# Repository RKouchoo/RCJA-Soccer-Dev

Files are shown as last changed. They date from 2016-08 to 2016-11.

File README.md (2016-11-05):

# RCJA Soccer Dev

#This projecta has now been abandoned as we are no longer using it for next season.
#please do not submit issues as we will not acknowledge them.

@Team Circut Breaker Dev

  First created: 3 / 7 / 2015
  Latest update: 25 / 8 / 2016

  Interesting Link: http://dlnmh9ip6v2uc.cloudfront.net/ - I love this link

  details about the compass sensor can be found on this data sheet http://dlnmh9ip6v2uc.cloudfront.net/datasheets/Sensors/Magneto/HMC5883L-FDS.pdf

  Latest code is being written in the Nationals2016 folder

  ===============
  CURRENT STATE:
  ===============

  WORKING ON CURRENTLY: Hard wiring the new light sensors to robot. Also working on a new check for system, with switches.

  ==============

  KICKER NOTICE:
  currently have not implemented methods for use of a soleniod+transformer/boost converter as i cannot mount it to either of the robots & and dangerous as a high current might get us disqualified (5 AMPS+ OUTPUT)
  
=====================================================  
========================================================

  TODO LIST:

Small Robot:

  - Mount compass
  - Mount kicker stuff
  - Mount booster circuit and work it out
  - write code for the compass to auto align when not much is happening (started compass intialisation)

Big Robot:
- Need to fix why sensors are fucking with us

After State:
  - Put compass on both robots
  
  - work on a random defence timer, robot going back into its half and then strafe defending. (Once compass is known to work, ill have to write stuff - cannot getting working til main movement code decides to work.
    to do with the headings....  oh noes.. requires advanced trig :/).

  - write code for the compass to auto align when not much is happening (started compass intialisation)

  - Dress robot make look pretty (Leds, Lasers, Protection etc)
  
  - create a heading compass system, later when we have two robots we NOTE: i have pre setup the variables
    can use the heading system for robots to return to original location

  CHANGELOG:

  - FIXED: "Issue where the robot will see different bars  behind it, so where 9 would be theres 2 or 9 and would make the robot spam left-right
    facing the wrong way"

    SOLUTION: the bars issue is still happening but has been resolved by changing directions in which the motors move. apparently the motor
    controllers do not like some movements and will go backwards !? kinda problematic.. will investigate after comp.
    
  - ADDED: speed control support for the motor controllers, so we dont tear apart the mat. 

  DROP LIST:

  - Not necessary: Re-Writing Main setup code in a seperate file, debunk the code issue and decide if its a hardware issue
  
  - Too Much overhead and takes CPU cycles: get serial screen working, outputting what would be in the console

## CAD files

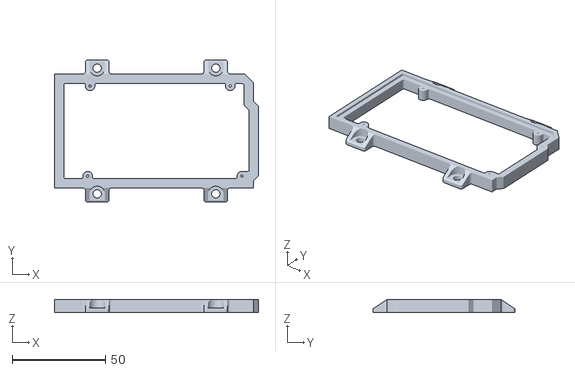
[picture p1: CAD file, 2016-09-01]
Print Files/MEGA_R2_MOUNT.STL
109.2 x 76.2 x 6.99

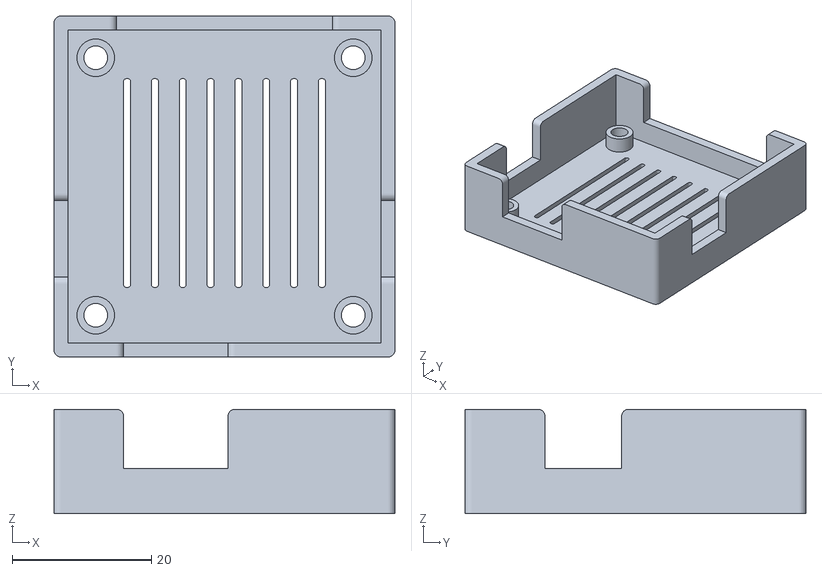
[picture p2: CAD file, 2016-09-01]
Print Files/L298N_-_Motor_driver_holder_-_heatsink.stl
49.0 x 49.0 x 15.0

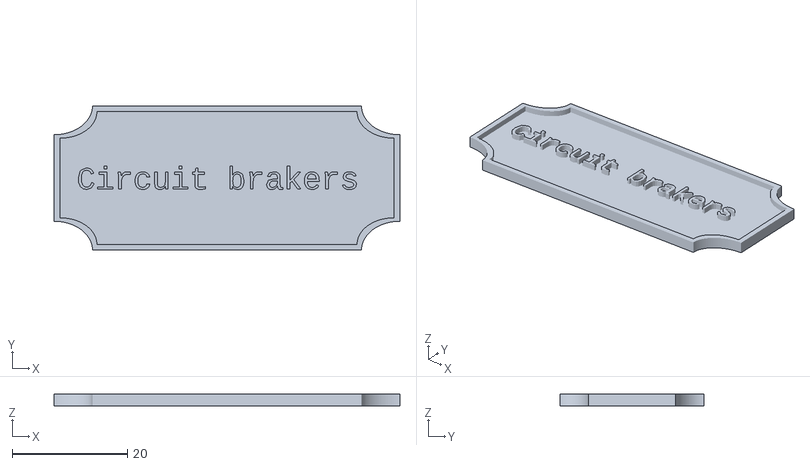
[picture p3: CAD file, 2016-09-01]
Print Files/nametag_20160831-16166-1kobh9q-0.stl
60.0 x 25.0 x 2.00

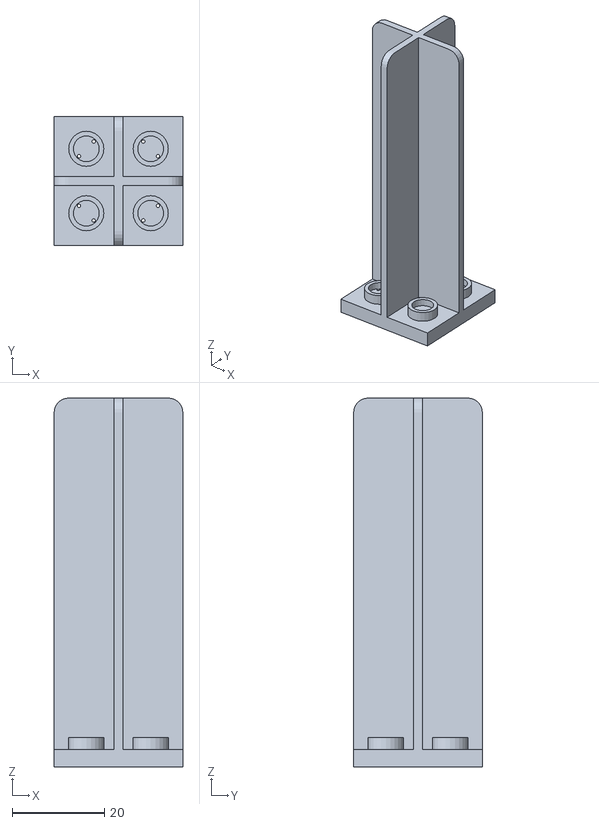
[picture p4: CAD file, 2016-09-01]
Print Files/Compass_Sketch.stl
27.9 x 27.9 x 80.0

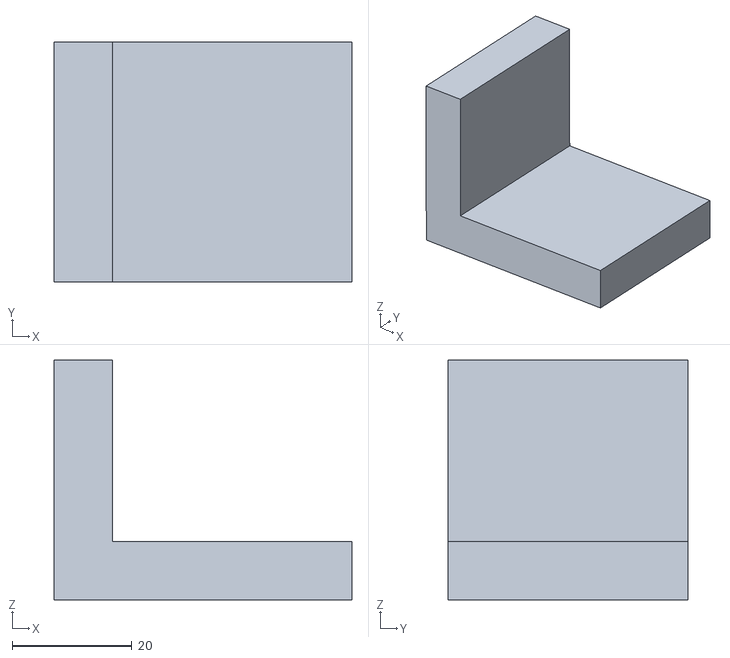
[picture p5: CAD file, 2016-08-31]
Print Files/angle_mount.obj
49.8 x 40.0 x 40.0

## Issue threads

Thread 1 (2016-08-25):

Bad Motor Controller

RKouchoo, 2016-08-25:
Motor controller will be replaced shortly

Closed 2016-08-31.

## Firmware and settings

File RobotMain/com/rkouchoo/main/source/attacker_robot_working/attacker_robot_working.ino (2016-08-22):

/*
 * Opens soccer robot main code set, 
 * Team circut breaker Dev @RKouchoo
 * 
 * First created:  5 / 8 / 2015
 * Latest Update:  22 / 8 / 2016
 * 
 * anything with a " // " next to it means it has been modified or its a comment!             | DAT BOI TEXT ART HERE PLZ |
 * 
 * 
 *        ===============================================
 *        PLEASE READ THE DOCUMENTATION FOR MORE INFO!!!!
 *        ===============================================
 * 
 * 
 */

                        //IMPORTS
 //=======================================================================
 
 #include <Wire.h>
                       //ROBOT MAP
//=======================================================================


  #define CompassAddress 0x1E //compass I2C addresses 
  #define CompassMode 0x02
  #define CompassReadMode 0x00
  #define CompassRegister 0x03
  #define CompassByteLength 6
 

  int CompassX; //compass headings
  int CompassY;
  int CompassZ; //current compass oreintation/direction
  int CompassOriginalDirection_Z; //the original direction that the compass starts in. stored at robot init, used to auto align (LATER OK :/ )

  //details about the compass can be found on this data sheet http://dlnmh9ip6v2uc.cloudfront.net/datasheets/Sensors/Magneto/HMC5883L-FDS.pdf
  
  const int LASER_PIN = 10;     //laser and led power up pins
  const int LED_PIN = 22;
  
  int LightsensorValue = 0;      //where the lightsensor input is stored
  const int LightsensorPin = A0; //lightsensor analog read pin
  int GREEN_VALUE = 2345567;     //colour values which need to be changed, depends on feild lighting !
  int WHITE_VALUE = 3534543;  
  
  boolean IsMovingLeft = false;  //true or false statements used for light sensor & movement
  boolean IsMovingRight = false;
  boolean IsMovingBackward = false;
  boolean IsMovingForward = false;
  
  int DefendCountdown = 10000000; //to be continued, look at documentation
  
  const int MotorMED_POWER = 150;  //can be used for motor setup functions max 255, -- will use when pwm cables are connected
  const int MotorFULL_POWER = 255;
  const int MotorLOW_POWER = 80;
                                
                                  //pwm speed and enable pins for the motor controllers
  const int Motor_EN_S_1_1 = 21;    
  const int Motor_EN_S_1_2 = 22; 
                                
  const int Motor_EN_S_2_1 = 23;
  const int Motor_EN_S_2_2 = 24;
  
  const int Motor1A = 38; //motor input pins A is forward, B is reverse  
  const int Motor1B = 40;
  
  const int Motor2A = 42;
  const int Motor2B = 44;
  
  const int Motor3A = 46;
  const int Motor3B = 48;
  
  const int Motor4A = 50;
  const int Motor4B = 52;

  const int LED_PWM_MAX_RATE = 255; //lighting stuff
  const int LED_PWM_MIN_RATE = 25;
  long LED_RAND;

  const int SOLENOID_PIN = 17; //future ref for transformer & kicker



//==================================================================

void RobotInitLights() {
  pinMode(LED_PIN, OUTPUT);
  LED_RAND = random(LED_PWM_MIN_RATE, LED_PWM_MAX_RATE);
  digitalWrite(LED_PIN, LED_RAND);
 }
 
void initlaser() {
 pinMode(LASER_PIN, OUTPUT);
 digitalWrite(LASER_PIN, HIGH);
}

//                          SEEKER
//==================================================================
#include <Wire.h>

/*
  IRSeeker.ino - A class for the HiTechnic IRSeeker V2 infrared sensor.
  Created by B. Blechschmidt, August 1, 2013.
  Edited by R. Kouchoo - STRICT USE FOR OUR ROBOT
  Clean version released into the public domain.
*/

struct InfraredResult
{
  byte Direction;
  byte Strength;
};

class InfraredSeeker
{
  public:
    static void Initialize();
    static boolean Test();
    static void ReadACRaw(byte* buffer);
    static void ReadDCRaw(byte* buffer);
    static InfraredResult ReadAC();
    static InfraredResult ReadDC();
    static int DirectionAngle(byte Direction);
  private:
    static InfraredResult PopulateValues(byte* buffer);
    static void ReadValues(byte OffsetAddress, byte* buffer);
    static const int Address = 0x10 / 2; //Divide by two as 8bit-I2C address is provided
};

void InfraredSeeker::Initialize()
{
  Wire.begin();
  Wire.beginTransmission(InfraredSeeker::Address);
  Wire.write(0x00);
  Wire.endTransmission();
  while(Wire.available() > 0)
    Wire.read();
}

boolean InfraredSeeker::Test()
{
  Wire.beginTransmission(InfraredSeeker::Address);
  Wire.write(0x08);
  Wire.endTransmission();
  Wire.requestFrom(InfraredSeeker::Address, 16);
  char Manufacturer_Model[16];
  while(Wire.available() < 16);
  for(byte i=0; i < 16; i++)
  {
    Manufacturer_Model[i] = Wire.read();
  }
  while(Wire.available() > 0)
    Wire.read();
  return strncmp(Manufacturer_Model, "HiTechncNewIRDir", 16)==0;
}

void InfraredSeeker::ReadValues(byte OffsetAddress, byte* buffer)
{
  Wire.beginTransmission(InfraredSeeker::Address);
  Wire.write(OffsetAddress);
  Wire.endTransmission();
  Wire.requestFrom(InfraredSeeker::Address, 6);
  while(Wire.available() < 6);
  for(byte i = 0; i < 6; i++)
  {
    buffer[i] = Wire.read();
  }
  while(Wire.available() > 0)
    Wire.read();
}

void InfraredSeeker::ReadACRaw(byte* buffer)
{
  ReadValues(0x49, buffer);
}

void InfraredSeeker::ReadDCRaw(byte* buffer)
{
  ReadValues(0x42, buffer);
}

InfraredResult InfraredSeeker::PopulateValues(byte* buffer)
{
  InfraredResult Data;
  Data.Direction = buffer[0];
  if(buffer[0] != 0)
  {
    if(buffer[0] % 2 == 0)
    {
      Data.Strength = (buffer[buffer[0] / 2] + buffer[buffer[0] / 2 + 1]) / 2;
    }
    else
    {
      Data.Strength = buffer[buffer[0] / 2 + 1];
    }
  }
  else
  {
    Data.Strength = 0;
  }
  return Data;
}

InfraredResult InfraredSeeker::ReadAC()
{
  byte buffer[6];
  ReadACRaw(buffer);
  return PopulateValues(buffer);
}

InfraredResult InfraredSeeker::ReadDC()
{
  byte buffer[6];
  ReadDCRaw(buffer);
  return PopulateValues(buffer);
}

int DirectionAngle(byte Direction)
{
  return Direction * 30 - 150;
}


//============================================================================================
//                                      Motor Functions

void Motor1FWD() {
  digitalWrite(Motor1A, HIGH);
  delay(50);
  digitalWrite(Motor1A, LOW);
}
void Motor1BACKWARD() {
  digitalWrite(Motor1B, HIGH);
  delay(50);  
  digitalWrite(Motor1B, LOW);
  
}

void Motor2FWD() {
  digitalWrite(Motor2A, HIGH);
  delay(50);
  digitalWrite(Motor2A, LOW); 
}
void Motor2BACKWARD() {
  digitalWrite(Motor2B, HIGH);
  delay(50);
  digitalWrite(Motor2B, LOW); 
}

void Motor3FWD() {  
  digitalWrite(Motor3A, HIGH);
  delay(50);
  digitalWrite(Motor3A, LOW);
}
void Motor3BACKWARD() {   
  digitalWrite(Motor3B, HIGH);
  delay(50);
  digitalWrite(Motor3B, LOW);
}


void Motor4FWD() {
  digitalWrite(Motor4A, HIGH);
  delay(50);
  digitalWrite(Motor4A, LOW);
}
 void Motor4BACKWARD() {
  digitalWrite(Motor4B, HIGH);
  delay(50);
  digitalWrite(Motor4B, LOW);
}

//==================================================================

void MoveFORWARD() {
Serial.println("FORWARD");
  digitalWrite(Motor1A, HIGH);
  digitalWrite(Motor2A, HIGH);
  digitalWrite(Motor3A, HIGH);
  digitalWrite(Motor4B, HIGH);
    
// digitalWrite(Motor3A, HIGH);
// digitalWrite(Motor4A, HIGH);

  delay(50);
  
  digitalWrite(Motor1A, LOW);   // digitalWrite(Motor3A, LOW);
  digitalWrite(Motor2A, LOW);   // digitalWrite(Motor4A, LOW);
  digitalWrite(Motor3A, LOW);
  digitalWrite(Motor4B, LOW);                                                                                                       
}

void MoveBACKWARD() {
  digitalWrite(Motor1B, HIGH);
  digitalWrite(Motor2B, HIGH);
  digitalWrite(Motor3B, HIGH);
  digitalWrite(Motor4A, HIGH); 
  delay(50);
  digitalWrite(Motor1B, LOW);
  digitalWrite(Motor2B, LOW);
  digitalWrite(Motor3B, LOW);
  digitalWrite(Motor4A, LOW);
}

void MoveBACKWARDRIGHT() {
  digitalWrite(Motor1B, HIGH);
  digitalWrite(Motor3B, HIGH);
  delay(50);
  digitalWrite(Motor1B, LOW);
  digitalWrite(Motor3B, LOW);
}

void MoveFORWARDRIGHT() {
  digitalWrite(Motor1A, HIGH);
  digitalWrite(Motor3A, HIGH);
delay(50);
  digitalWrite(Motor1A, LOW);
  digitalWrite(Motor3A, LOW);
}


void MoveFORWARDLEFT() {
  digitalWrite(Motor2A, HIGH);
  digitalWrite(Motor4B, HIGH);
delay(50);
  digitalWrite(Motor2A, LOW);
  digitalWrite(Motor4B, LOW);
}
void MoveBACKWARDLEFT() {
  digitalWrite(Motor2B, HIGH);
  digitalWrite(Motor4A, HIGH);
delay(50);
  digitalWrite(Motor2B, LOW); 
  digitalWrite(Motor4A, LOW);
}

void MoveSIDEWAYSRIGHT() {
  digitalWrite(Motor2B, HIGH);
  digitalWrite(Motor3A, HIGH);
  digitalWrite(Motor1A, HIGH);
  digitalWrite(Motor4B, HIGH);
  delay(50);
  digitalWrite(Motor2B, LOW);
  digitalWrite(Motor3A, LOW);
  digitalWrite(Motor1A, LOW);
  digitalWrite(Motor4B, LOW); 
  }

void MoveSIDEWAYSLEFT() {
  digitalWrite(Motor2B, HIGH);
  digitalWrite(Motor4A, HIGH);
  digitalWrite(Motor1B, HIGH);
  digitalWrite(Motor3A, HIGH);
  delay(50);
  digitalWrite(Motor2B, LOW);
  digitalWrite(Motor4A, LOW);
  digitalWrite(Motor1B, LOW);
  digitalWrite(Motor3A, LOW);
  
}

void TurnLEFT() {
  digitalWrite(Motor1A, HIGH);
  digitalWrite(Motor4B, HIGH);
  digitalWrite(Motor2B, HIGH);//
  digitalWrite(Motor3B, HIGH); 
  delay(50); 
  digitalWrite(Motor1A, LOW);
  digitalWrite(Motor4B, LOW);
  digitalWrite(Motor2B, LOW);
  digitalWrite(Motor3B, LOW);//
}

void TurnRIGHT() {
  digitalWrite(Motor2A, HIGH);
  digitalWrite(Motor3B, HIGH);
  digitalWrite(Motor1A, HIGH);
  digitalWrite(Motor4A, HIGH);// 
  delay(50); 
  digitalWrite(Motor2A, LOW);
  digitalWrite(Motor3B, LOW);
  digitalWrite(Motor1A, LOW);
  digitalWrite(Motor4A, LOW);//  
}

 //==========================================================================


void setup() {
  Serial.begin(9600);
   
  RobotInitLights();
  initlaser();
  InfraredSeeker::Initialize();
  
  //initialise compass
  Wire.begin();
  Wire.beginTransmission(CompassAddress); //open comms to the compass
  Wire.write(CompassMode); //select mode register
  Wire.write(CompassReadMode); //continuous measurement mode
  Wire.endTransmission();
  
  Wire.beginTransmission(CompassAddress);
  Wire.write(CompassRegister); //select register 3, X MSB register, these valuses were found on the data sheet.
  Wire.endTransmission();

  //request data from the comnpass
  Wire.requestFrom(CompassAddress, CompassByteLength);

  //request data and set original direction, will be used for auto correct in the future.
  
  if(CompassByteLength<=Wire.available()){
    CompassOriginalDirection_Z = Wire.read()<<8; //Z msb
    CompassOriginalDirection_Z |= Wire.read(); //Z lsb
  }
  
  else;
  {
  Wire.end();
  }
  
  //will create a large amount of delay, try not to use
  Serial.println("DEBUG: Compass start rotation = " + CompassOriginalDirection_Z);
  
  pinMode(Motor1A, OUTPUT);
  pinMode(Motor1B, OUTPUT);
  pinMode(Motor2A, OUTPUT);
  pinMode(Motor2B, OUTPUT);
  pinMode(Motor3A, OUTPUT);
  pinMode(Motor3B, OUTPUT);
  pinMode(Motor4A, OUTPUT);
  pinMode(Motor4B, OUTPUT);

  Serial.println("HiTechnic IRSeeker V2 Initialised, robot has been initialised, loop program will now commence !"); 
  
}

//==========================================================================
    
 //                            I===========I
 //                            I-MAIN LOOP-I
 //                            I===========I 
  
//===========================================================================
  void loop() {

  InfraredResult InfraredBall = InfraredSeeker::ReadAC();
  byte Direction = InfraredBall.Direction;

  //Tell the Compass where to begin reading  directional data
  Wire.beginTransmission(CompassAddress);
  Wire.write(CompassRegister); //select register 3, X MSB register
  Wire.endTransmission();

   Wire.requestFrom(CompassAddress, CompassByteLength);
  
  if(CompassByteLength<=Wire.available()){
    CompassX = Wire.read()<<8; //X msb
    CompassX |= Wire.read(); //X lsb
    
    CompassZ = Wire.read()<<8; //Z msb
    CompassZ |= Wire.read(); //Z lsb
    
    CompassY = Wire.read()<<8; //Y msb
    CompassY |= Wire.read(); //Y lsb
  }

//===========================================================================  
  
  //true and false conditionals setup
  
  boolean IsMovingLeft = false;
  boolean IsMovingRight = false;
  boolean IsMovingBackward = false;
  boolean IsMovingForward = false;
/*
   Serial.println("LightSensor value = " + LightsensorValue);

   //LIGHT & Movement
  
   LightsensorValue = analogRead(LightsensorPin);
  //cond combo 1
   if (LightsensorValue == WHITE_VALUE) 
   {
    if (IsMovingLeft = true)
    {
    MoveFORWARDRIGHT(); 
    Serial.println("boolean - IsMovingLeft - MoveFORWARDRIGHT()");
    }
   }
  //cond combo 2
   if (LightsensorValue == WHITE_VALUE) 
   {
    if (IsMovingRight = true)
    {
    MoveFORWARDLEFT();
    Serial.println("boolean - IsMovingRight - MoveFORWARDLEFT()"); 
    }
   }
  //cond combo 3
   if (LightsensorValue == WHITE_VALUE) 
   {
    if (IsMovingForward = true) 
    {
    MoveBACKWARD();
    Serial.println("boolean - IsMovingForward - MoveBACKWARD()");       
    }
   } 
 */
//==========================================================================


  
   if (InfraredBall.Direction == 1) 
  {                                                                          
  TurnRIGHT();
  Serial.println("TurnLEFT 1");
  boolean IsMovingLeft = true;
  //boolean IsMovingRight = false;
  //boolean IsMovingBackward = false;
  //boolean IsMovingForward = false;
  } 
  
  if (InfraredBall.Direction == 2)
  {
  TurnRIGHT();  
  Serial.println("TurnLeft 2");  //STRAFE HERE  
  boolean IsMovingLeft = true;
  //boolean IsMovingRight = false;
  //boolean IsMovingBackward = false;
  //boolean IsMovingForward = false;
  }
  
  if (InfraredBall.Direction == 3)
  {
  MoveFORWARDLEFT();
  Serial.println("MoveFORWARDLEFT 3");
  boolean IsMovingLeft = true;
  //boolean IsMovingRight = false;
  //boolean IsMovingBackward = false;
  //boolean IsMovingForward = false;
  }
  
  if (InfraredBall.Direction == 4)
  {
  MoveFORWARD();
  Serial.println("MoveFORWARD 4");
  //boolean IsMovingLeft = false;
  //boolean IsMovingRight = false;
  //boolean IsMovingBackward = false;
  boolean IsMovingForward = true;
  }
  
  if (InfraredBall.Direction == 5)
  {
  MoveFORWARD();
  Serial.println("MoveFORWARD 5");
  //boolean IsMovingLeft = false;
  //boolean IsMovingRight = false;
  //boolean IsMovingBackward = false;
  boolean IsMovingForward = true;
  }
  
  if (InfraredBall.Direction == 6)
  {
  MoveFORWARD();
  Serial.println("MoveFORWARD 6");
  //boolean IsMovingLeft = false;
  //boolean IsMovingRight = false;
  //boolean IsMovingBackward = false;
  boolean IsMovingForward = true; 
  }
  
  if (InfraredBall.Direction == 7)
  {
  MoveFORWARDRIGHT(); 
  Serial.println("MoveFORWARDRIGHT 7"); 
  //boolean IsMovingLeft = false;
  boolean IsMovingRight = true;
  //boolean IsMovingBackward = false;
  //boolean IsMovingForward = false;
  }
  
  if (InfraredBall.Direction == 8)
  {
  TurnLEFT();
  Serial.println("TurnRight 8");  //STRAFE HERE
  //boolean IsMovingLeft = false;
  boolean IsMovingRight = true;
  //boolean IsMovingBackward = false;
  //boolean IsMovingForward = false;
  }
  
  if (InfraredBall.Direction == 9)
  {
  TurnLEFT();
  Serial.println("TurnRIGHT 9");
  //boolean IsMovingLeft = false;
  boolean IsMovingRight = true;
  //boolean IsMovingBackward = false;
  //boolean IsMovingForward = false;
  }

//==================================================================

  if (InfraredBall.Direction == 0)
  {
  Serial.println("Yo theres no ball !?!??! - TurnRIGHT()");
  TurnRIGHT();
  boolean IsMovingRight = true;

  }  
}

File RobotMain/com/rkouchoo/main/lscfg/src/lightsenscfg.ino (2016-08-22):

#include <Arduino.h>

int sensorPin = A0; // select the input pin for ldr
int sensorValue = 0; // variable to store the value coming from the sensor
int buttonIn = 6;
int buttonOut = 5;
int laser = 10;

void setup() {
  pinMode(buttonIn, INPUT);
    pinMode(buttonOut, OUTPUT);
    pinMode(laser, OUTPUT);
Serial.begin(9600); //sets serial port for communication
}
void loop() {
  digitalWrite(buttonOut, HIGH);
  digitalWrite(laser, HIGH);

sensorValue = analogRead(sensorPin); // read the value from the sensor
Serial.println(sensorValue); //prints the values coming from the sensor on the screen

//delay(1000);
}

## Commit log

2016-08-22 many many changes.
    - Support for speed control
    - reversed motor orientations in loop
    - data logging is under way
    - partially wrote lightsensor movement
    - trying to fix turn functions when sensor approaches near
    you can find the main class at:
    /RobotMain/com/rkouchoo/main/Atom-PlatIO/src/attacker_robot_working.ino
    I have changed to Atom IDE with PlatIO as it is easier to integrate and write code in, with intelligent completion.
    [Documentation.ino, OpenSource.ino, Robot_Code_simple_test.ino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]
2016-08-24 Fixed Speed Control, fixed delay
    Fixed robot speed control with analogWrite and delay has been moved to bottom of the loop.
    [Documentation.ino, attacker_robot_working.ino]
2016-08-25 Added new code for smaller robot
    - added motor ports
    - added setup and loop
    * currently adding seeker class
2016-08-25 Added Motor speed support
    currently working movements
2016-08-25 Added Updated movement control.
    didn't add to main class as was written on a separate machine. will merge soon
    [updated_movement_control.ino]
2016-08-31 added new file to 3D print
    angle mounts for velcro walls
    [angle_mount.obj]
2016-09-01 Added My current files for 3D printing
    [Compass_Sketch.stl, L298N_-_Motor_driver_holder_-_heatsink.stl, MEGA_R2_MOUNT.STL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]
2016-09-01 FixedTestFor Ball Added CheckIfHasBall
    added CheckIfHasBall, fixed test for ball
    [SmallAttacker.ino]
2016-09-01 fixed a bug
    boolean HasBall = false;
    was originally set to true
    [SmallAttacker.ino]
2016-09-08 fixed a bug
    random 'z' placed
    [DefendAttacker.ino]
2016-09-08 Updated 2 bugs.
    realised that the beambreak sensor will be inverted
    [DefendAttacker.ino, SmallAttacker.ino]
2016-09-09 Updated to use only compass align for debug
    testing compass align once it has been wired up
